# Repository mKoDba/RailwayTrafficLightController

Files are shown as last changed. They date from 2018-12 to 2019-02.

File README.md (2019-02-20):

# Railway Traffic Light Controller
Railway Traffic Light Controller Project

This is a faculty project for the fall semester of year 2018/2019 done at FEUP (Faculdade de Engenharia da Universidade do Porto) as part of the course Eletronic Systems/Sistemas Electrónicos (SELE).

Authors are Joel Vaz and Mario Kodba.

Goals of the project are:

- design a robust railway traffic light control system, which controls one green and one red light, based on a microcontroller ATMEGA328p

- use two types of communication protocols (synchronous and asynchronous)

- use memory testing algorithms

- follow and stick to particular coding guideline (for example MISRA C)

- use professional development methodology: project management, proper debugging techniques, use of version control

- design and implement the laboratorial prototype using LEDS, sensors and microcontroller

- design electrical scheme and PCB industrial prototype using EAGLE CAD

TODO:
* finish memory testing
* add i2c timeout if not detected
* add watchdog

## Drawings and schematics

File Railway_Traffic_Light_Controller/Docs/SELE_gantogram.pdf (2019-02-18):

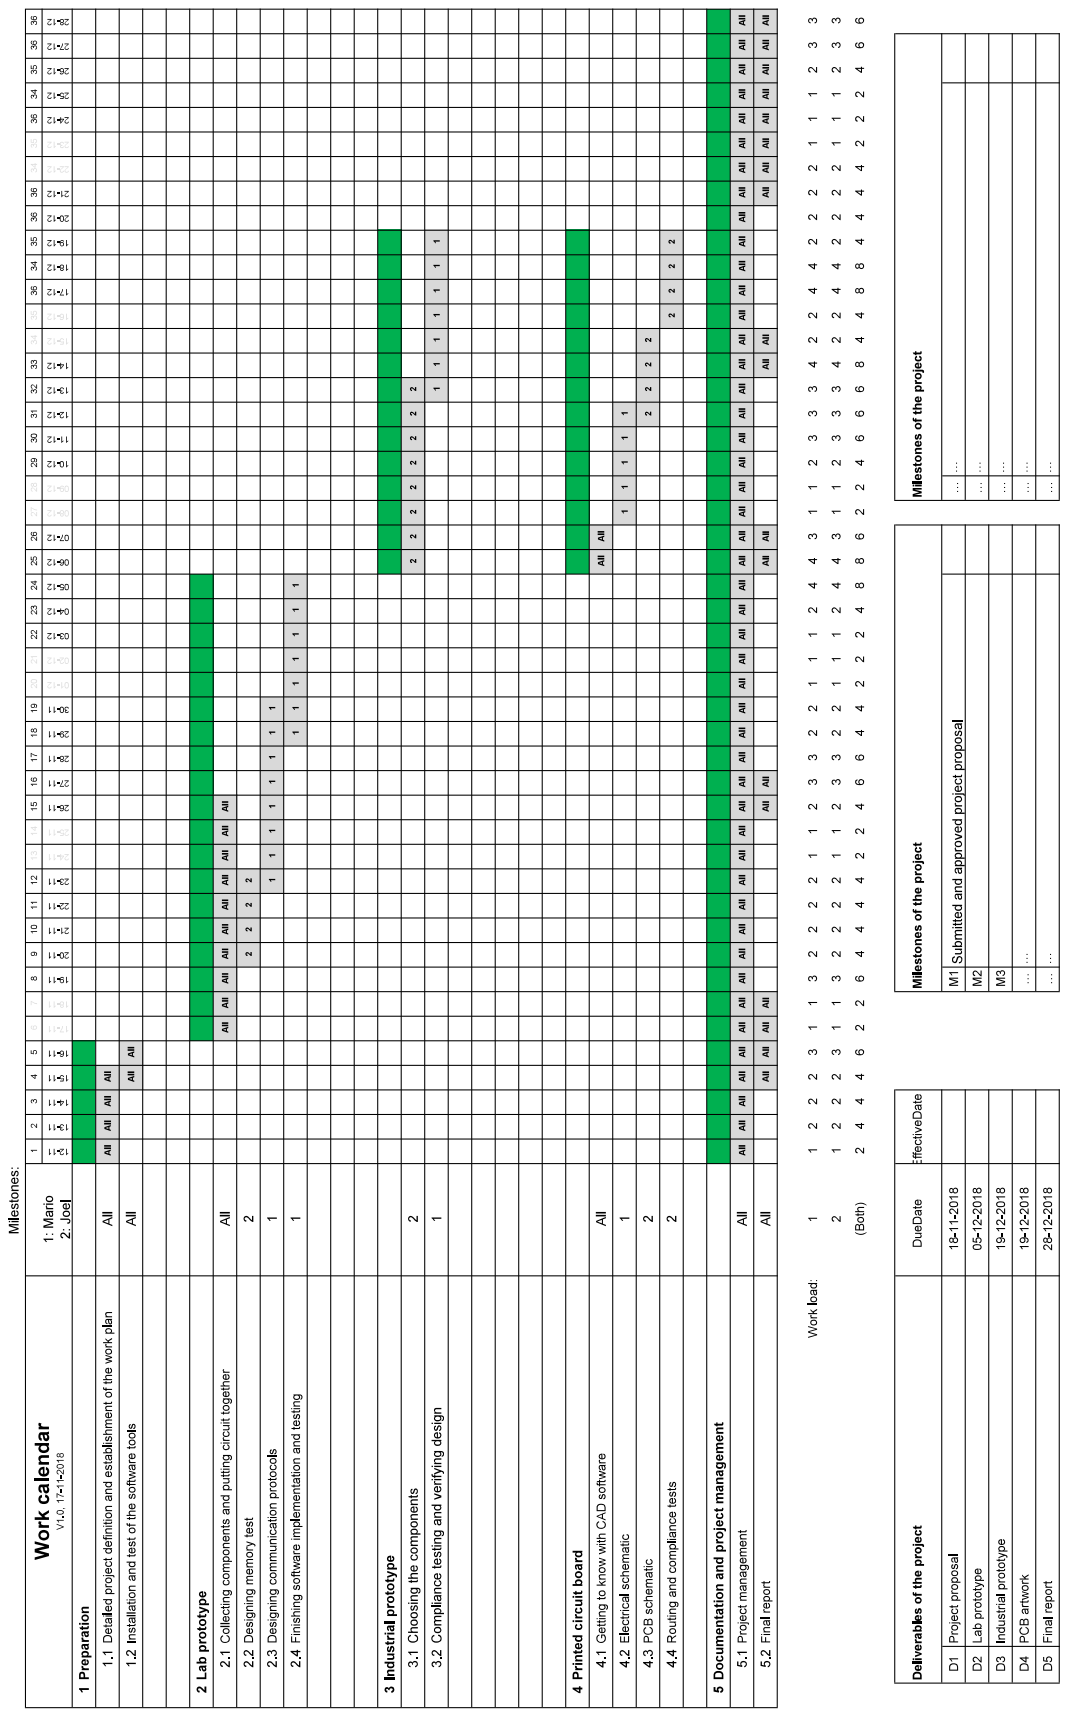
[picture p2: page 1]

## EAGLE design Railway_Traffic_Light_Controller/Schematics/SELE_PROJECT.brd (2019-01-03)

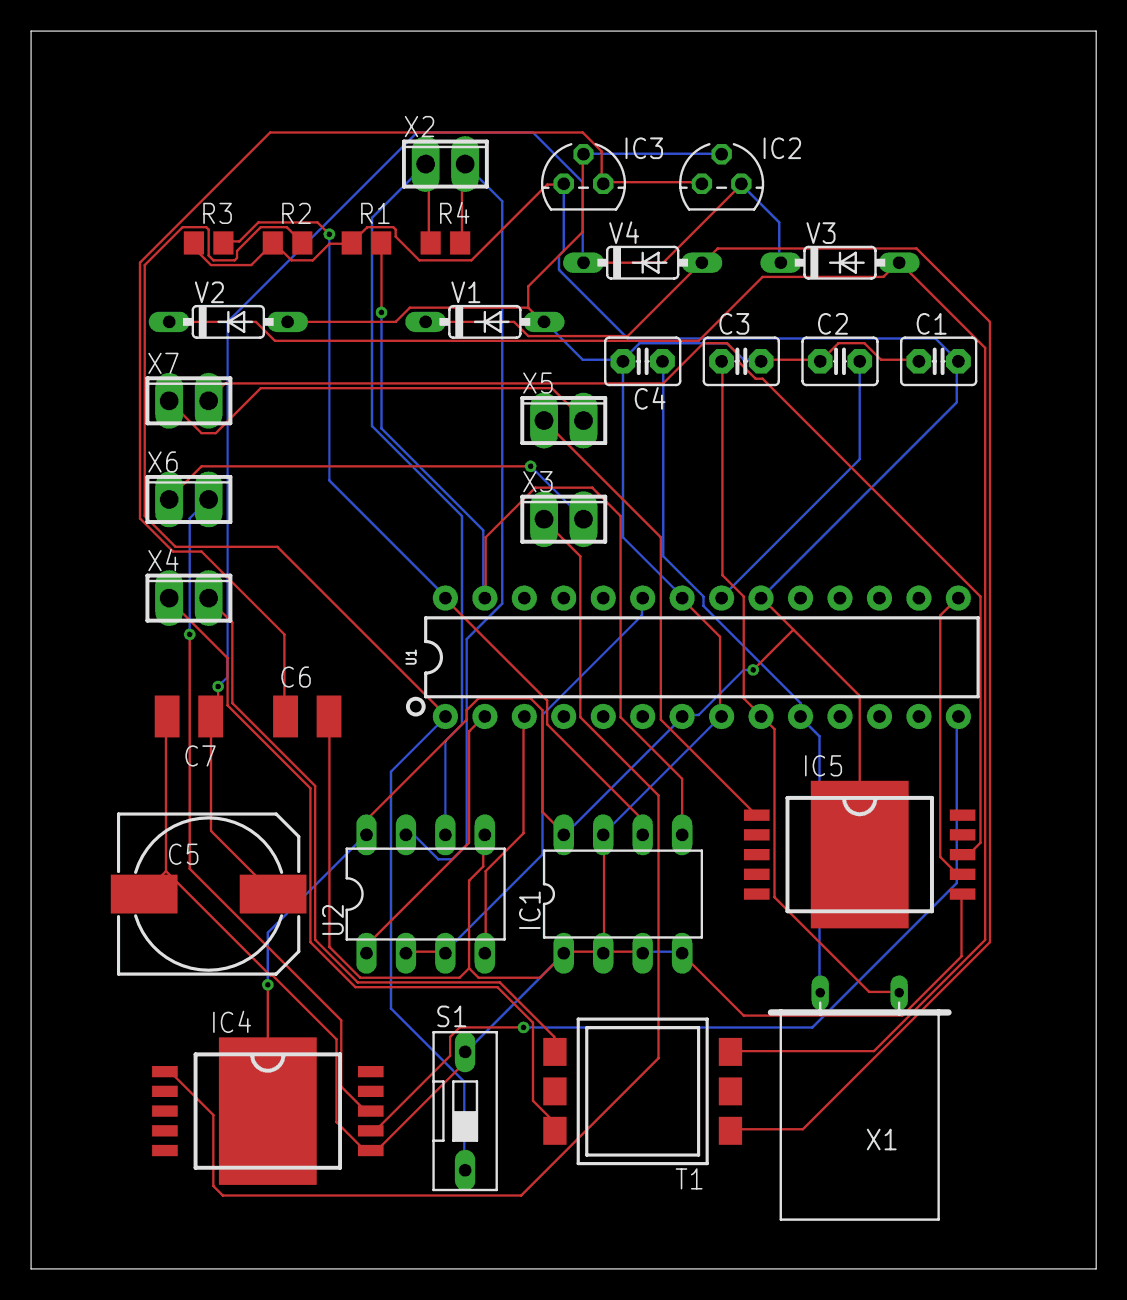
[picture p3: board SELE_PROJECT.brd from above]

Board: 2 copper layers, 68.6 x 79.7 mm, 31 parts (0 on the bottom side), 27 nets.

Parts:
C1, C2: 100n; C2.5-3
C3, C4: 22p; C2.5-3
C5: 1500u/35V; 150CLZ-1010
C6, C7: 0.1u; C1210
IC1: D1 (24LC1025); DIL08
IC2: D2 (7812L); TO92
IC3: D3 (7805L); TO92
IC4, IC5: VN460SP; POWER-SO10
R1, R3: 10k; R0805
R2: 47k; R0805
R4: 120; R0805
S1: DS-01
T1: 230V to 12V AC; SM-EP7
U1: 328P; MICROCONTROLLER_DIP28
U2: LTC485N; DIL08
V1, V2, V3, V4: 1N4148DO35-7; DO35-7
X1: 16MHz; Q
X2: 2POL254
X3, X5: LAMP CONNECTOR; 2POL254
X4, X6, X7: 230V AC CONNECTOR; 2POL254

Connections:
GND: C1.1, C2.1, C3.2, C4.2, C5.-, C6.2, C7.2, IC1.1, IC1.2, IC1.3, IC1.4, IC1.7, IC2.2, IC3.2, IC4.6, IC5.6, S1.2, U1.8, U1.22, U2.5, V1.A, V2.A
unnamed: C4.1, U1.10, X1.2
unnamed: U1.2, U2.1
unnamed: IC1.5, R1.2, U1.27
unnamed: U1.3, U2.4
unnamed: IC1.6, R3.2, U1.28
unnamed: R4.1, U2.6, X2.1
unnamed: U1.23, U2.2, U2.3
unnamed: R2.2, S1.1, U1.1
unnamed: R4.2, U2.7, X2.2
unnamed: C2.2, U1.21
unnamed: T1.6, V1.C, V4.A
unnamed: T1.4, V2.C, V3.A
unnamed: T1.1, X4.1
unnamed: T1.2, T1.3, X4.2
unnamed: IC4.7, U1.14
unnamed: C5.+, C7.1, IC2.3, V3.C, V4.C
unnamed: C6.1, IC2.1, IC3.3
unnamed: IC5.7, U1.15
unnamed: IC4.1, X3.1
unnamed: IC5.1, X5.1
unnamed: IC4.8, X6.2
unnamed: X3.2, X6.1
unnamed: IC5.8, X7.2
unnamed: X5.2, X7.1
VCC: C1.2, IC1.8, IC3.1, IC4.P, IC5.P, R1.1, R2.1, R3.1, U1.7, U1.20, U2.8
X1: C3.1, U1.9, X1.1

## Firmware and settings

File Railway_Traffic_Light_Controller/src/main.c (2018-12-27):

/*********************************************************************************
 *                                                                               *
 *               Reliable Light System Controller For Train Line                 *
 *                                                                               *
 *                                                                               *
 *               Code guide: NASA C style guide 1994                             *
 *                                                                               *
 *               Authors: Joel Matos Vaz (joelmatosvaz@gmail.com)                *
 *                        Mario Kodba (up201802785@fe.up.pt)                      *
 *               Institution: @Faculdade de Engenharia Universidade do Porto     *
 *                                                                               *
 ********************************************************************************/
/*
*
*	Algorithm: 1 ) Computer main station sends data with slave address
*			   2 ) Micro controller receives the commands and evaluates if address is correct
*			   3 ) Sends the data to the memory I2C with time stamp
*			   4 ) Sends the data to the corresponding output LEDs
*			   5 ) If test mode enable begins testing the memory
*/
#include "../includes/config.h"
#include "../includes/serial_comms.h"
#include "../includes/i2c_comms.h"
#include "../includes/ram_test.h"
#include "../includes/flash_test.h"
#include "../includes/controller.h"

int main(void) {

	//initates the modules
	uart_init();
	set_output_signals();
	controller_init();
	i2c_init();
                
    char cmdServer[6]={}; // Serial communication array 2 bits ID and 4 bits message
	char write_i2c_enable[1]={};

	uint16_t totalCmd = 1;			
    uint8_t i = 0;
    uint8_t addr[256] = {};
	uint8_t controller_enable = 0;

	stdout = &uart_output;
    stdin  = &uart_input;

    while(1) {
    	uint8_t lastaddr = read_last_address(EXT_MEM);
    	memset(cmdServer,0,sizeof(cmdServer));
		
		//SERIAL COMMUNICATION CODE STARTS HERE
		printf("Mem address:%d\n",lastaddr);
        printf("Slave id = 01\nCommand Number = %d \nReceive Mode enabled!\n", totalCmd);
        uart_getstring(cmdServer);
		printf("ID = %c %c - - - - - - - - - - Full Command = ", cmdServer[0], cmdServer[1]);
		totalCmd = totalCmd + 1;
		for(i = 0; i < 6; i++){
        	printf("%c ", cmdServer[i]);    
		}
		printf("\n");
		if(cmdServer[0] == '0' && cmdServer[1] == '1'){
			printf("\nMicro controller with id 01 Received: \n");
			printf("Message: ");
			controller_enable = 1; //enables controller logic
			for(i = 0; i < 4; i++){
				printf("%c ",cmdServer[i+2]);
			}
		printf("\n \n");
		}
		else{
			printf("\n");
			printf("Incorrect slave id: ");
			controller_enable = 0; //Safety redundancy
			for(i = 0; i < 2; i++){
				printf("%c", cmdServer[i]);
			}
			printf("\n \n");
		} 
		//SERIAL COMMUNICATION CODE ENDS HERE
		/////////////////////////////////////////////////////////////////////////////////////////////////
		
		/////////////////////////////////////////////////////////////////////////////////////////////////
		//CONTROLLER CODE STARTS HERE
		if(controller_enable == 1){
			if(cmdServer[2] == 48 && cmdServer[3] == 48 && cmdServer[4] == 48 && cmdServer[5] == 48){
				light_red_on();
				light_green_off();
				printf("Red On\n");
				byte_write_eeprom(EXT_MEM,lastaddr,0);		//if RED, writes 0 to eeprom
				controller_enable = 0;
				if(lastaddr<MEM_CAP){
					lastaddr++;
				}
				else lastaddr=0x01;
			}
			else if (cmdServer[2] == 49 && cmdServer[3] == 49 && cmdServer[4] == 49 && cmdServer[5] == 49){
				light_red_off();
				light_green_on();
				printf("Green On\n");
				byte_write_eeprom(EXT_MEM,lastaddr,1);		//if GREEN, writes 1 to eeprom
				controller_enable = 0;
				if(lastaddr<MEM_CAP){
					lastaddr++;
				}
				else lastaddr=0x01;
			}
			//Memory Testing mode
			else if (cmdServer[2] == 48 && cmdServer[3] == 49 && cmdServer[4] == 48 && cmdServer[5] == 49){
				////////////////// MEMORY TESTING ///////////
				printf("Testing Mode\n");
				//wdt_initiate();
				uint8_t ram_errors = ram_test();
    			printf("RAM memory test showed %d errors.\n", ram_errors);
    			if(flash_test()) 
					printf("FLASH memory test detected errors. \n");
    			else 
					printf("FLASH memory ok.");
    			////////////////////////////////////////////////////////
			}
			//Print EEPROM LOG
			else if (cmdServer[2] == 48 && cmdServer[3] == 48 && cmdServer[4] == 49 && cmdServer[5] == 49){
				////////////////// EEPROM PRINT ///////////
				printf("Print EEPROM memory values? (0-No / 1-Yes): \n");
				uart_getstring(write_i2c_enable);
				printf("%c\n", write_i2c_enable[0]);

				if(write_i2c_enable[0] == '1'){
					read_eeprom(EXT_MEM, &addr[0]); 
					printf("ADDRESS --- VALUE STORED\n\n");

					for(i=0;i<MEM_CAP;i++){
						printf("%d --- %d\n", i, addr[i]);
					}
					write_i2c_enable[0] = 0;
				}
			}
			//Unkown Command
			else{
				printf("Not Recognizable Command\n");
				byte_write_eeprom(EXT_MEM,lastaddr,100);		//put value 100 when error detected, for easy detection
				controller_enable = 0;
				if(lastaddr<MEM_CAP){
					lastaddr++;
				}
				else lastaddr=0x01;
			}//end else if
		}//end control enable logic
		//CONTROLLER CODE ENDS HERE
		/////////////////////////////////////////////////////////////////////////////////////////////////

		//EEPROM CONTROL CODE STARTS HERE
		/////////////////////////////////////////////////////////////////////////////////////////////////
		//uses address 0x00 of eeprom to save address value of last writing, in case of power off
		byte_write_eeprom(EXT_MEM,0x00,lastaddr);
		//EEPROM CONTROL CODE ENDS HERE
		/////////////////////////////////////////////////////////////////////////////////////////////////

		printf("\n-------------------------------------------------\n");
    } //End While(1)
	return 0; 
}//end Main

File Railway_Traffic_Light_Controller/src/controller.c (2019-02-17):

/*********************************************************************************
 *                                                                               *
 *               Controller Functions                                            *
 *                                                                               *
 *                                                                               *
 *               Code guide: NASA C style guide 1994                             *
 *                                                                               *
 *               Authors: Joel Matos Vaz (joelmatosvaz@gmail.com)                *
 *                        Mario Kodba (up201802785@fe.up.pt)                      *
 *               Institution: @Faculdade de Engenharia Universidade do Porto     *
 *                                                                               *
 ********************************************************************************/
/*
*
*Code for controlling the lights
*Emergence mode red and green both on and blinking
*
*/
#include "../includes/config.h"
#include "../includes/controller.h"

void set_output_signals(void){
    DDRB |= ((1<<Red_light) | (1<<Green_light));
}

//////////////////////////////////////////////////////////////////////////////////

void controller_init(void){
        PORTB |= ((1<<Red_light) | (0<<Green_light));
}

//////////////////////////////////////////////////////////////////////////////////

void light_red_on(void){
        PORTB |= (1<<Red_light);
}

//////////////////////////////////////////////////////////////////////////////////

void light_red_off(void){
    PORTB &= ~(1<<Red_light);
}

/////////////////////////////////////////////////////////////////////////////////

void light_green_on(void){
    PORTB |= (1<<Green_light);
}

//////////////////////////////////////////////////////////////////////////////////

void light_green_off(void){
    PORTB &= ~(1<<Green_light);
}

//////////////////////////////////////////////////////////////////////////////////

void emergence_mode(void){
    PORTB |= ((1<<Red_light) | (0<<Green_light)); 
}

//////////////////////////////////////////////////////////////////////////////////

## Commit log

2018-11-21 Added the main structural project files
    A simple Main.c that uses the ATMEGA328p internal clock and turns on a LED
    EEPROM simple memory pattern test, reads and writes into the EEPROM
    Configuration file for the project
2018-12-05 added i2c communication protocol
2018-12-05 added header files for i2c
2018-12-05 added i2c testing, pointer to input string
2018-12-05 Fixed some bugs on i2c. Noticed that VS code is set up for ATMEGA328pb need to change
    [main.c]
2018-12-10 Add files via upload
    Schematic drawing with uC, EEPROM and PC serial communication
    -missing lamp interface
    [SELE_PROJECT.sch]
2018-12-10 Updated file folders
    [SELE_PROJECT.sch]
2018-12-10 Fixed a small bug
    [i2c_comms.c, main.c, serial_comms.c]
2018-12-11 Updated controller.c code and fixed bug in main.c
    [controller.c, main.c]
2018-12-12 # WARNING: head commit changed in the meantime
    Merge branch 'master' of
    https://github.com/sobakaAxolotl/RailworkController
    Conflicts:
    Reliable_Controller_For_Railworks/inc/serial_comms.h
    Reliable_Controller_For_Railworks/src/main.c
    Reliable_Controller_For_Railworks/src/serial_comms.c
2018-12-12 Added i2c enable signal
2018-12-12 Controller Logic implemented. Updated TODO file. Fixed bug in Serial communication.
    [controller.c, main.c]
2018-12-12 added i2c_init to main.c
2018-12-17 Fixed Led on&off function bug. TO FIX - > I2C blocks the main cycle.
    [controller.c, main.c]
2018-12-17 minor fix for printing
    [main.c]
2018-12-17 minor printing fixes
2018-12-17 added cmdServer cleaning values as it wasn't receiving correct values when
    [main.c]
2018-12-18 added saving address on power off + debug changes
2018-12-18 updated electrical schematic
    [SELE_PROJECT.sch]
2018-12-18 schematic update
    [SELE_PROJECT.sch]
2018-12-18 updated schematic
    [SELE_PROJECT.sch]
2018-12-18 Implemented watch dog timer.
2018-12-27 Minor bug fix and implementation of log printing in a server command
    [SELE_PROJECT.brd, SELE_PROJECT.sch]
2019-01-03 Finish
    Finish Project
    [SELE_PROJECT.brd]
